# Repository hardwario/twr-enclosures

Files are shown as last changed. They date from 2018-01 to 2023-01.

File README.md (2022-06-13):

<a href="https://www.hardwario.com/">HARDWARIO Logo</a>

# HARDWARIO Enclosures

This repository contains Openscad and STL models of HARDWARIO IoT Kit enclosures. These model have been optimized for 3D printing.

# Overview

The following table lists the available models:

| _____Model/Preview | STL Model | _____Module/setup | #Layers | #Mini | #Standard | #Tag | I/O Terminal | Antenne | USB | Compatibility |
| --- | --- | --- | --- | ----- | --- | ---- | --- | --- | --- | --- |
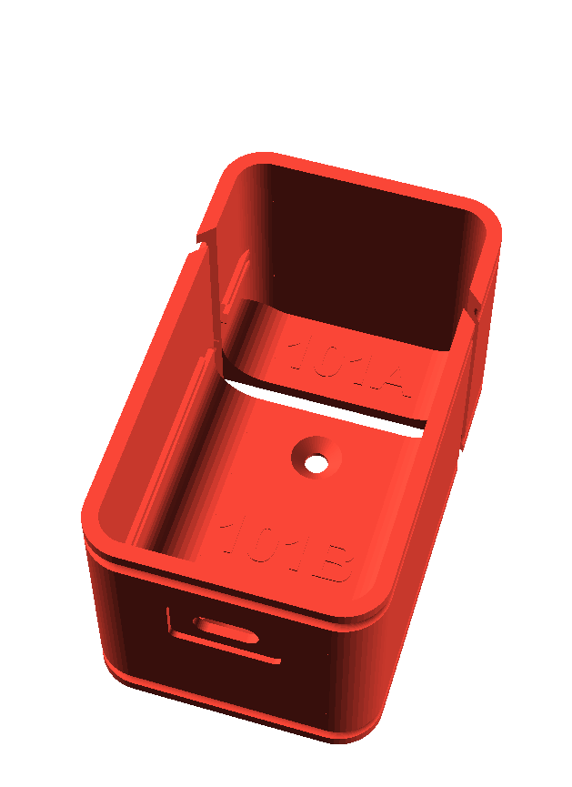
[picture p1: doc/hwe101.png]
|  | HWE101A<br>HWE101B | Mini Battery<br>Core<br>Mini Cover\* | 3 | 3 | \- | \- | \- | \- | Yes | |
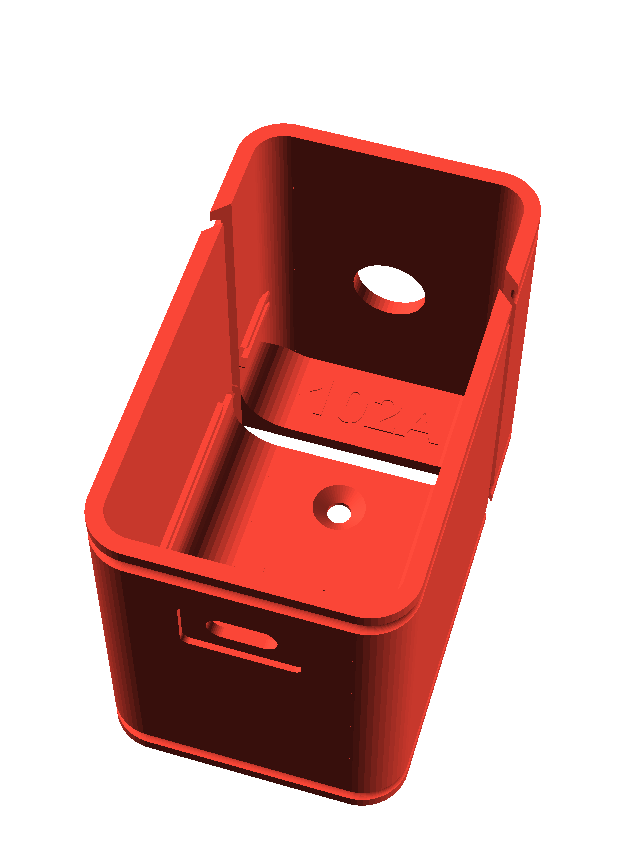
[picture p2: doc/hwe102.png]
|  | HWE102A<br>HWE102B | Mini Battery<br>LoRa / Sigfox<br>Core<br>Mini Cover\* | 4 | 4 | \- | \- | \- | Yes | Yes | |
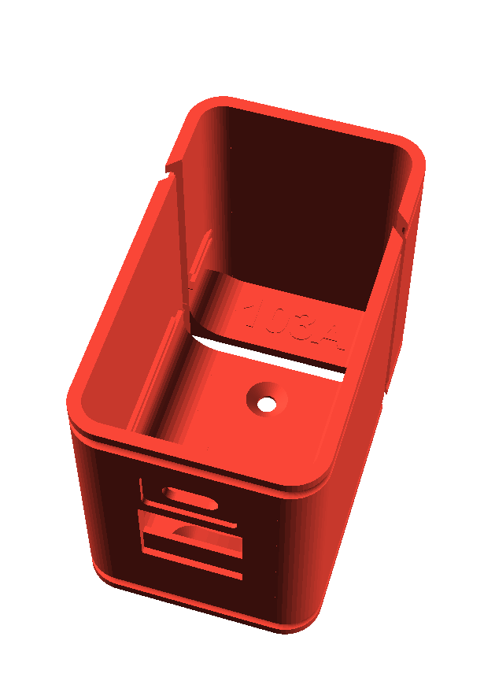
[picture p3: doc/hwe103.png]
|  | HWE103A<br>HWE103B | Mini Battery<br>RS-485<br>Core<br>Mini Cover\* | 4 | 4 | \- | \- | 4P/3.5 mm | \- | Yes | 1-Wire R1.1<br>Sensor R1.0 |
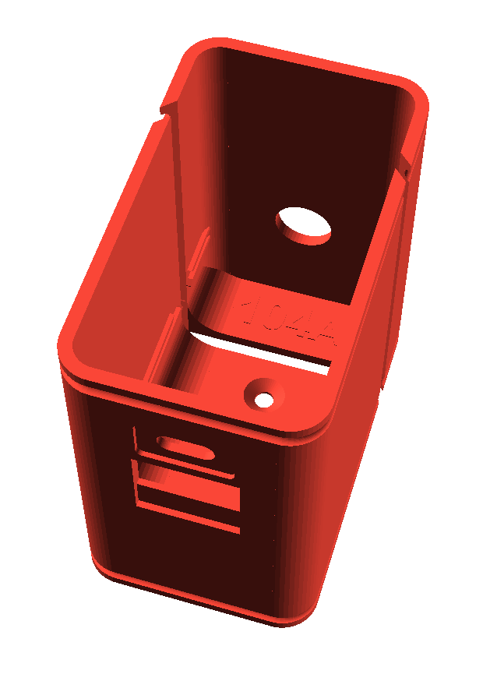
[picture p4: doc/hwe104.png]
|  | HWE104A<br>HWE104B | Mini Battery<br>LoRa / Sigfox<br>RS-485<br>Core<br>Mini Cover\* | 5 | 5 | \- | \- | 4P/3.5 mm | Yes | Yes | 1-Wire R1.1<br>Sensor R1.0 |
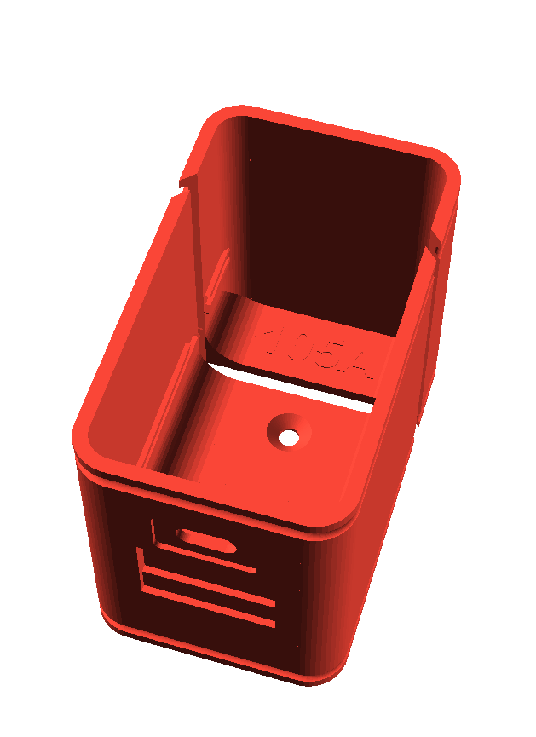
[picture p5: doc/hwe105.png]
|  | HWE105A<br>HWE105B | Mini Battery<br>Sensor R1.1<br>Core<br>Mini Cover\* | 4 | 4 | \- | \- | 5P/3.5 mm | \- | Yes | |
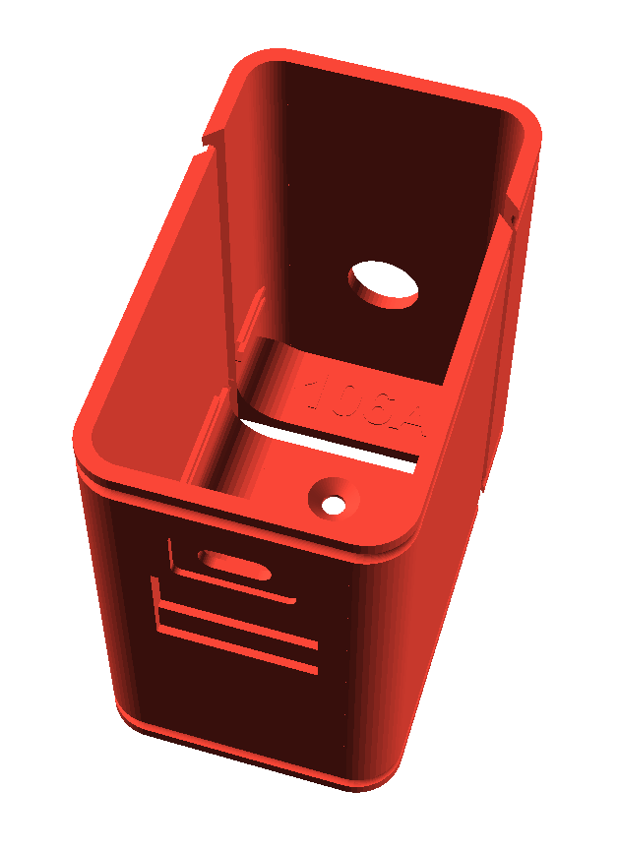
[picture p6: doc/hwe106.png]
|  | HWE106A<br>HWE106B | Mini Battery<br>LoRa / Sigfox<br>Sensor R1.1<br>Core<br>Mini Cover\* | 5 | 5 | \- | \- | 5P/3.5 mm | Yes | Yes | |
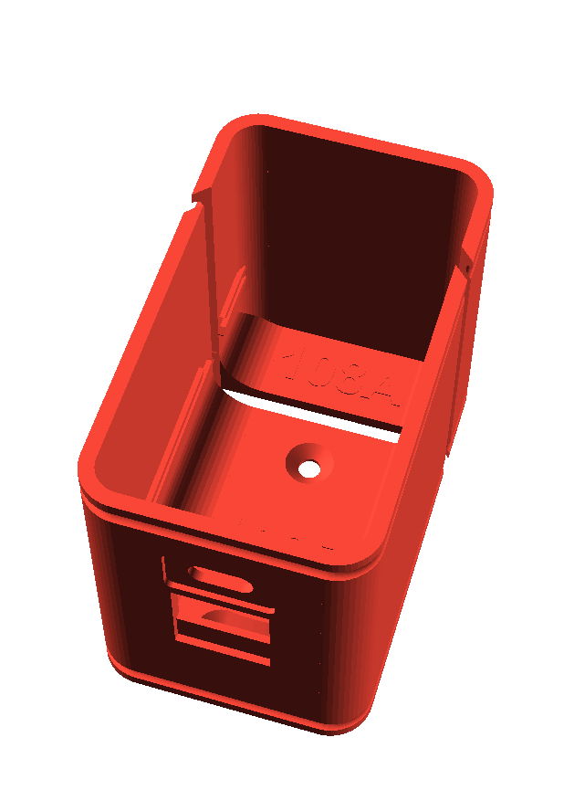
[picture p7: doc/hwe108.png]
|  | HWE108A<br>HWE108B | Mini Battery<br>Relay<br>Core<br>Mini Cover\* | 4 | 4 | \- | \- | 3P/3.81 mm | \- | Yes | |
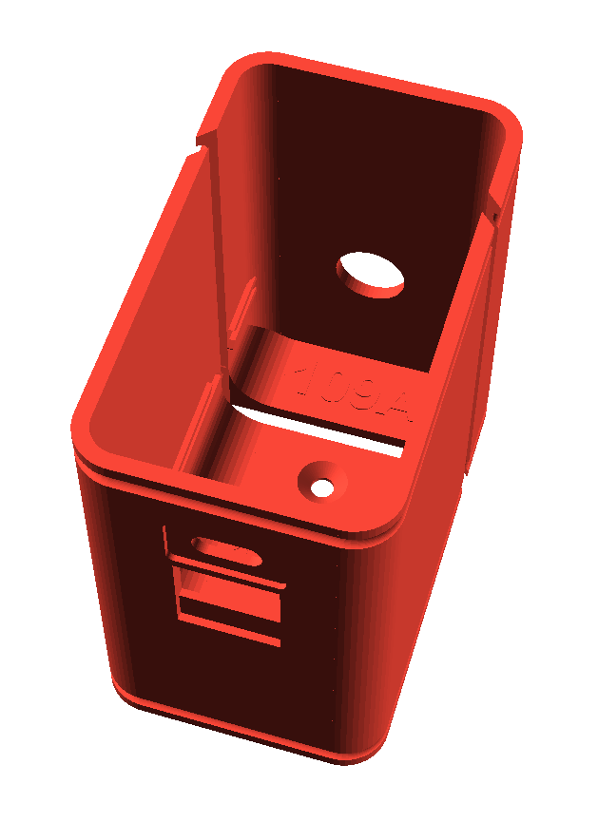
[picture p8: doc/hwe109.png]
|  | HWE109A<br>HWE109B | Mini Battery<br>LoRa / Sigfox<br>Relay<br>Core<br>Mini Cover\* | 5 | 5 | \- | \- | 3P/3.81 mm | \- | Yes | |
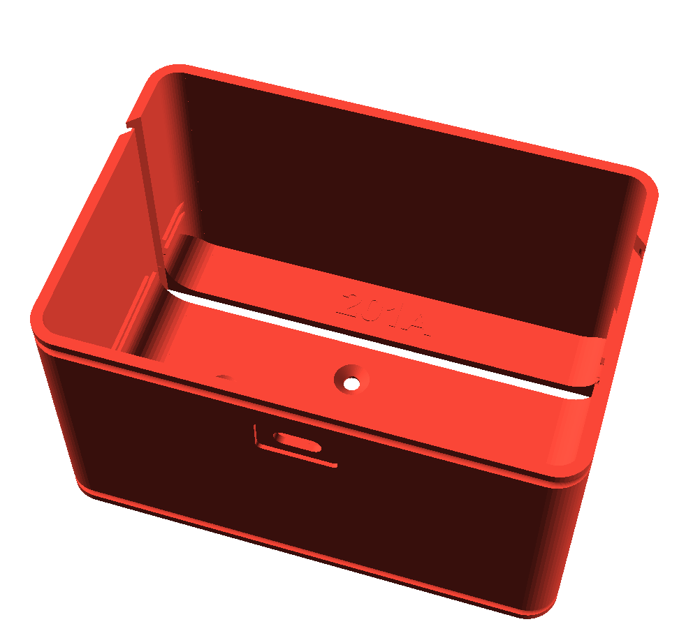
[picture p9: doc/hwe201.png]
|  | HWE201A<br>HWE201B | Battery<br>CO2 (+ 3xTag)<br>Core<br>Cover | 4 | 4 | 1 | 3 | \- | \- | Yes | |
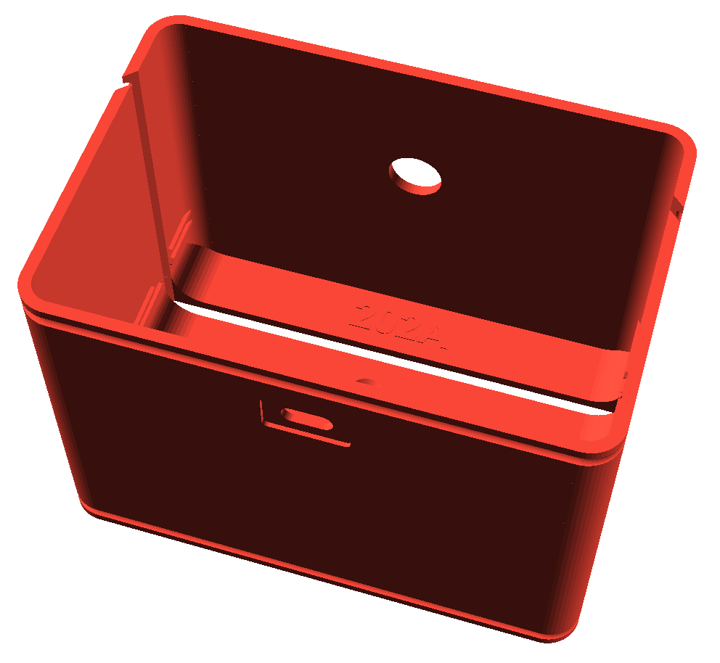
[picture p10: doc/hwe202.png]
|  | HWE202A<br>HWE202B | Battery<br>CO2 (+ 3xTag)<br>LoRa / Sigfox<br>Core<br>Cover | 5 | 5 | 2 | 3 | \- | Yes | Yes | |
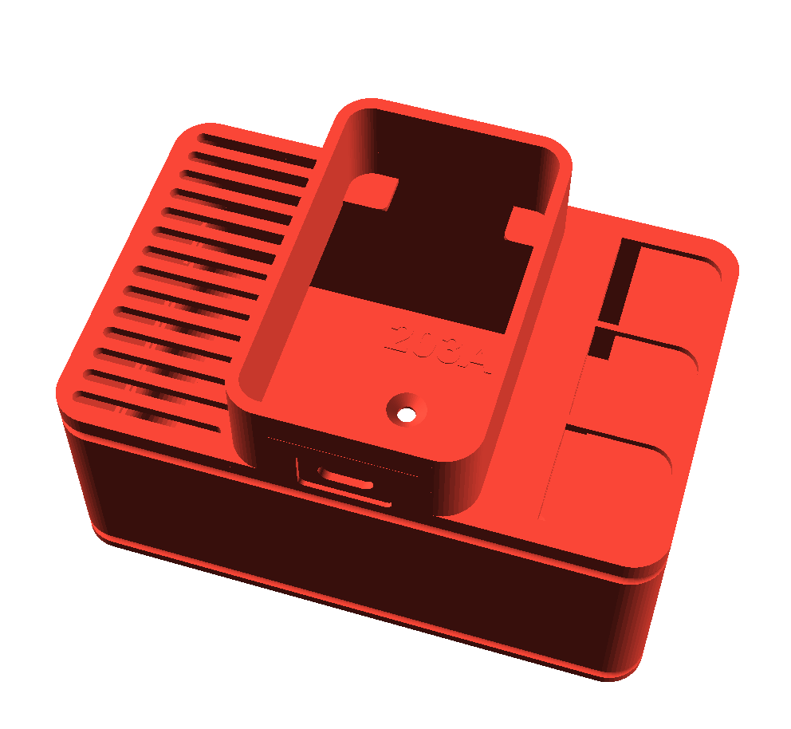
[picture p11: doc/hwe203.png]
|  | HWE203A<br>HWE203B | Battery<br>CO2 (+3xTag inner)<br>Core<br>LCD\* | 4 | 4 | 2 | 3 | \- | \- | Yes | |
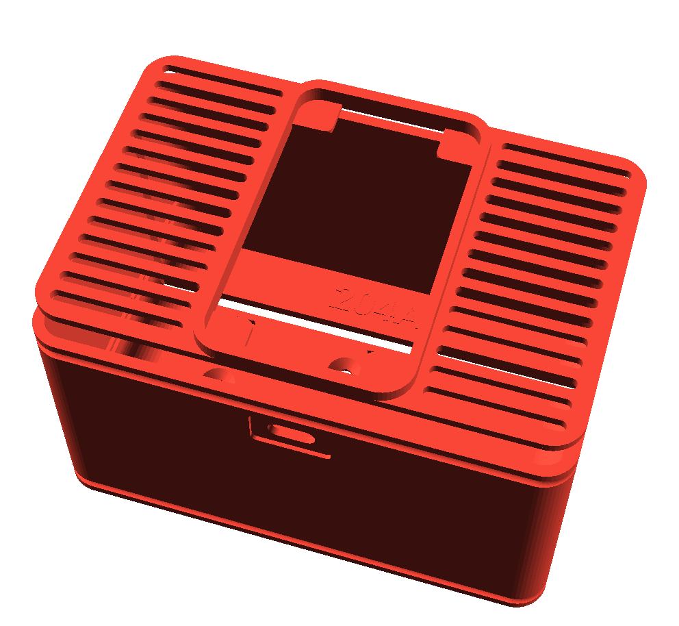
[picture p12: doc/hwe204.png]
|  | HWE204A<br>HWE204B<br>HWE204C | Battery<br>CO2 (+ 3xTag)<br>Core<br>LCD\* | 4 | 4 | 2 | 3 | \- | \- | Yes | |
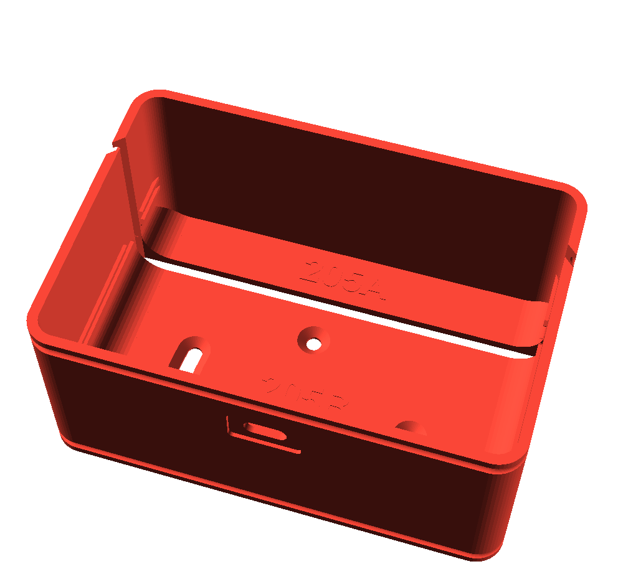
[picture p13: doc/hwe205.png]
|  | HWE205A<br>HWE205B | Battery (+ 1xTag)<br>Core<br>Cover | 3 | 3 | 1 | 1 | \- | \- | Yes | |
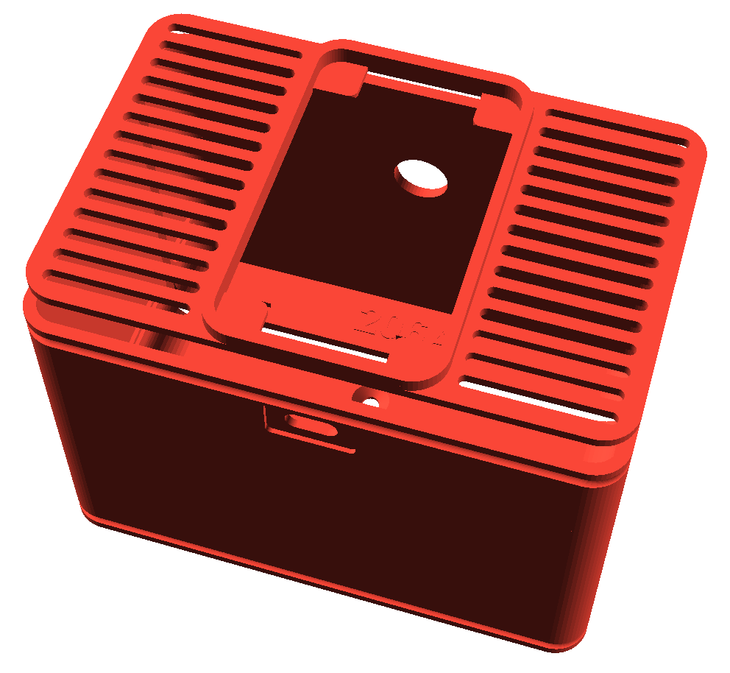
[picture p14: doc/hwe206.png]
|  | HWE206A<br>HWE206B<br>HWE206C | Battery<br>CO2 (+ 3xTag)<br>LoRa / Sigfox<br>Core<br>LCD\* | 5 | 5 | 3 | 3 | \- | Yes | Yes | |
|  | HWE207A<br>HWE207B | Battery<br>LoRa / Sigfox<br>Core<br>Cover\* | 4 | 2 | 2 | 1 | \- | Yes | Yes | |
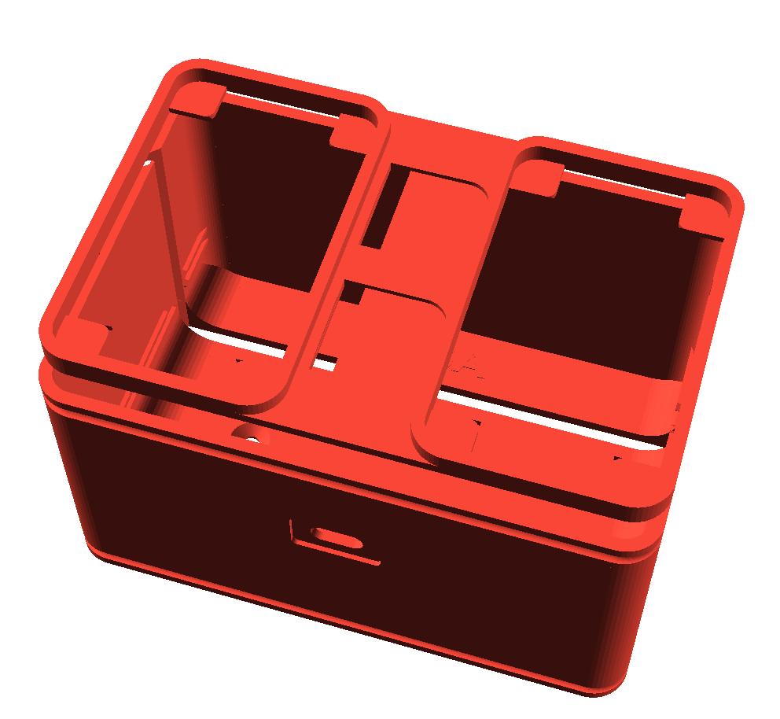
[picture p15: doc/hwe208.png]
|  | HWE208A<br>HWE208B<br>HWE208C | Battery (+ 1xTag)<br>Core<br>Split<br>LCD\* & Climate\* (+ 2xTag) | 4 | 4 | 3 | 3 | \- | No | Yes | |
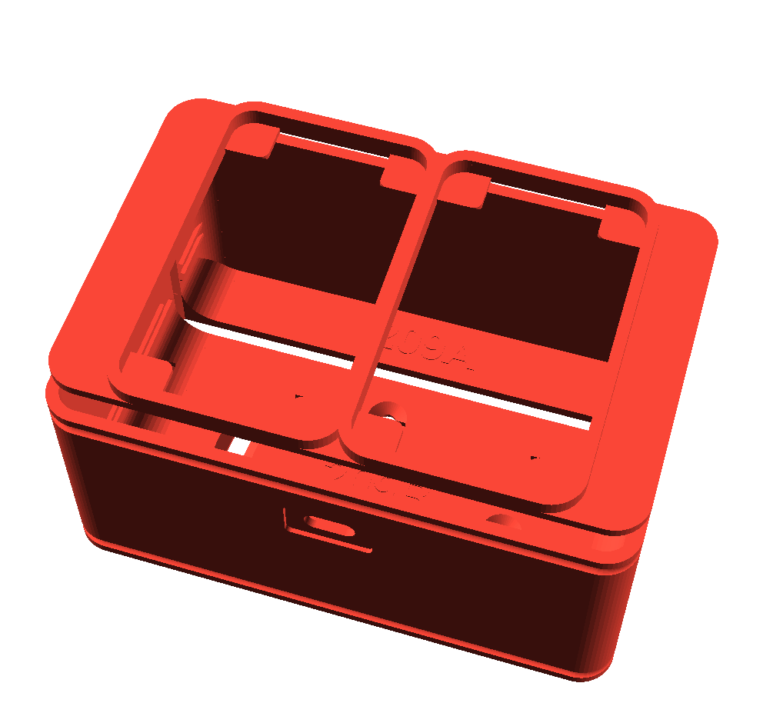
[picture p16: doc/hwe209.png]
|  | HWE209A<br>HWE209B<br>HWE209C | Battery (+ 1xTag)<br>Core<br>Compact Split<br>LCD\* & Climate\* | 4 | 4 | 3 | 1 | \- | No | Yes | |
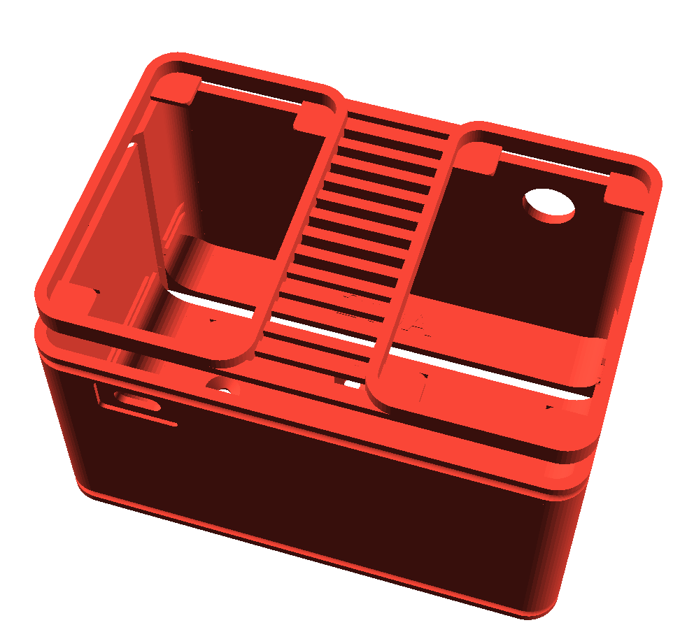
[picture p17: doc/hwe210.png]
|  | HWE210A<br>HWE210B<br>HWE210C | Battery (+ 1xTag)<br>Split<br>Core & LoRa / SF<br>LCD\* & Climate\*  | 4 | 4 | 3 | 1 | \- | Yes | Yes | |
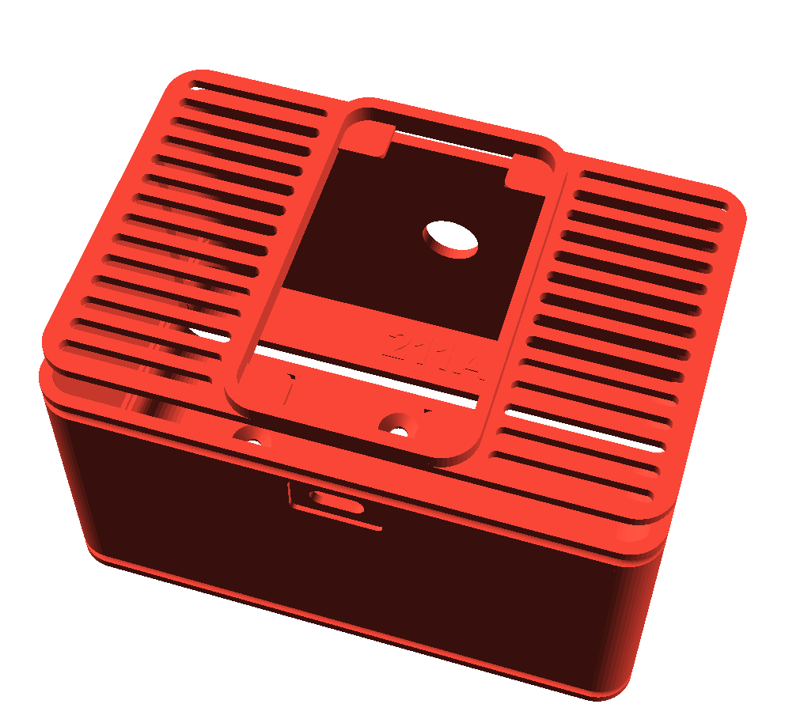
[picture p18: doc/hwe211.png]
|  | HWE211A<br>HWE211B<br>HWE211C | Battery (+ 1xTag)<br>LoRa / Sigfox<br>Core<br>LCD\* | 4 | 4 | 3 | 1 | \- | \- | Yes | |
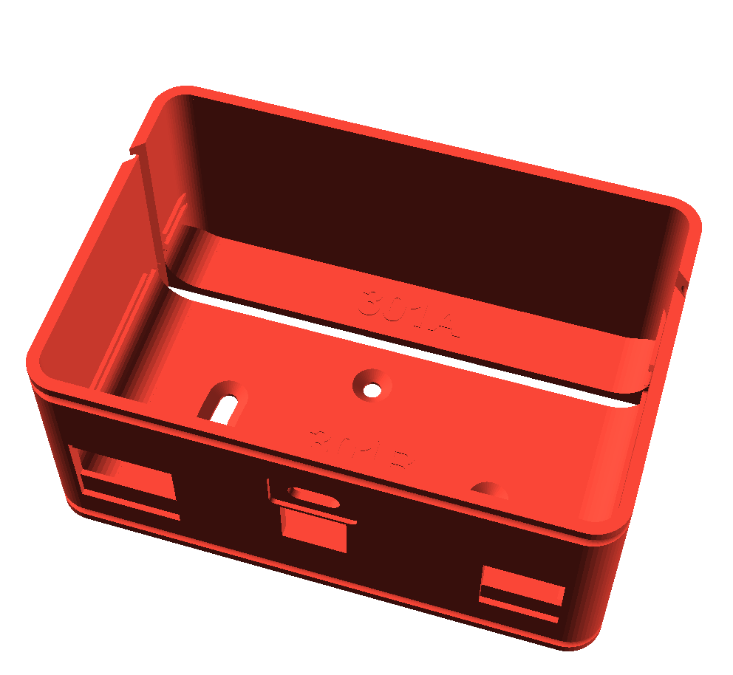
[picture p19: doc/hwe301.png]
|  | HWE301A<br>HWE301B | Power (+ 2xTag)<br>Core<br>Cover | 3 | 3 | 1 | 2 | 3P/3.81 mm 3P/5.0 mm | \- | Yes | |
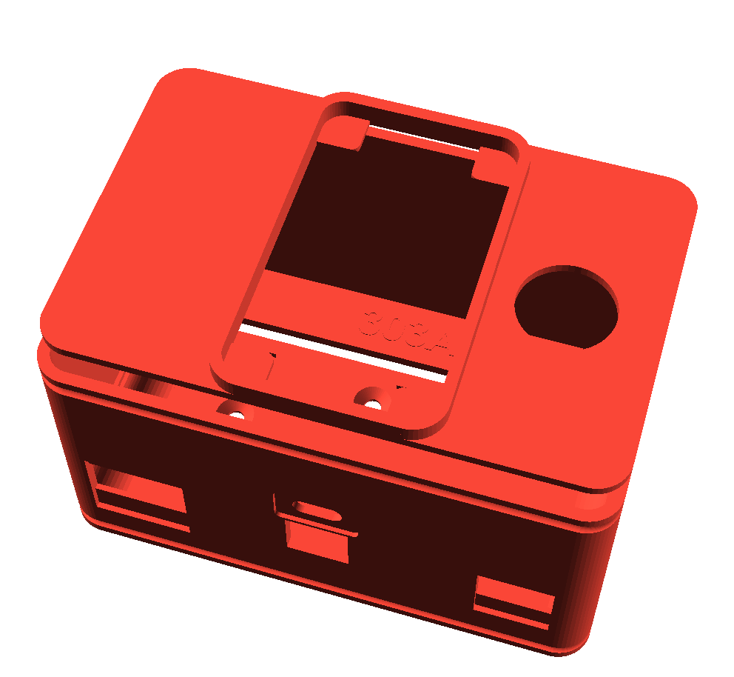
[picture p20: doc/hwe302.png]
|  | HWE302A<br>HWE302B<br>HWE302C | Power (+ 2xTag)<br>Core<br>Encoder | 3 | 3 | 1 | 2 | 3P/3.81 mm 3P/5.0 mm | \- | Yes | |
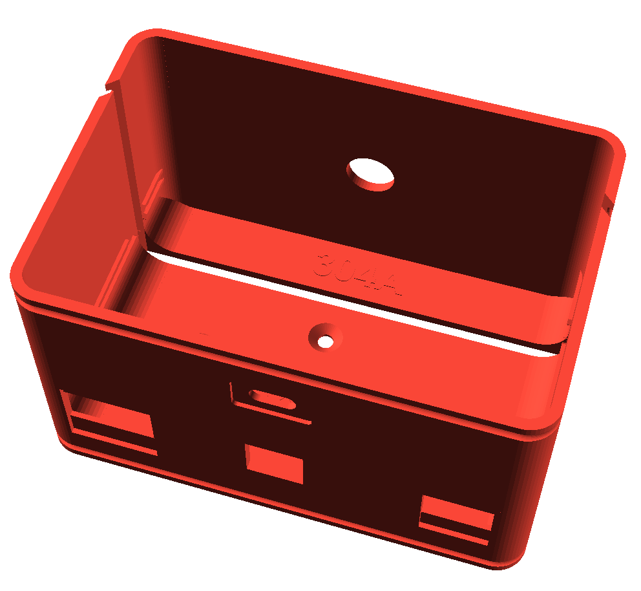
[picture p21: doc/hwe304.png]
|  | HWE304A<br>HWE304B | Power (+ 2xTag)<br>LoRa / Sigfox<br>Core<br>Cover | 4 | 4 | 2 | 2 | 3P/3.81 mm 3P/5.0 mm | Yes | Yes | |
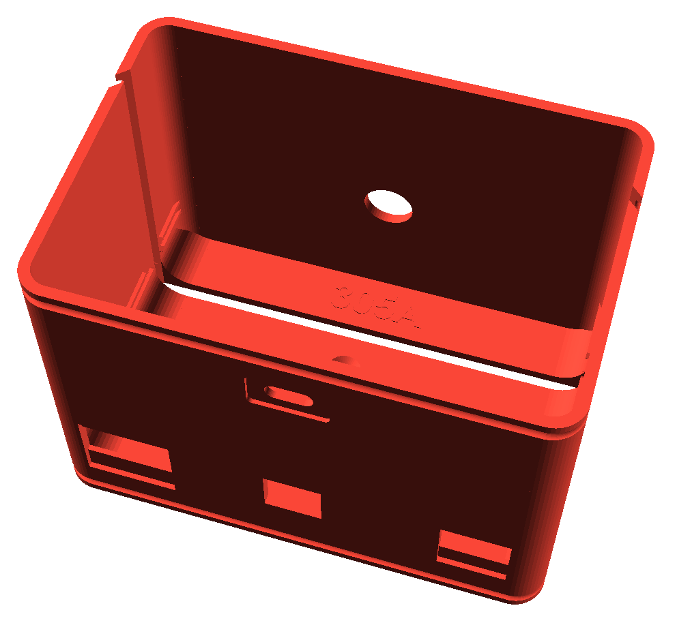
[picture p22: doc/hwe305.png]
|  | HWE305A<br>HWE305B | Power (+ 2xTag)<br>LoRa / Sigfox<br>CO2 (+ 3xTag)<br>Core<br>Cover | 5 | 3 | 2 | 5 | 3P/3.81 mm 3P/5.0 mm | Yes | Yes | |
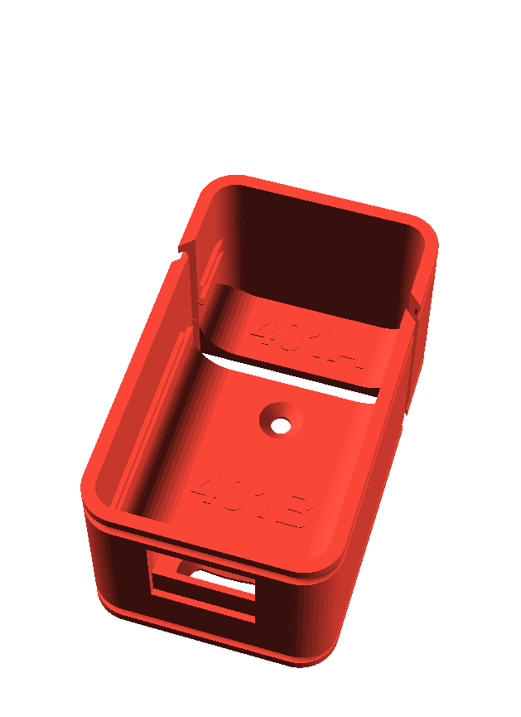
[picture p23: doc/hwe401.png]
|  | HWE401A<br>HWE401B | 1-Wire<br>Climate | 2 | 2 | 2 | \- | 4P/3.5 mm | \- | \-  | |
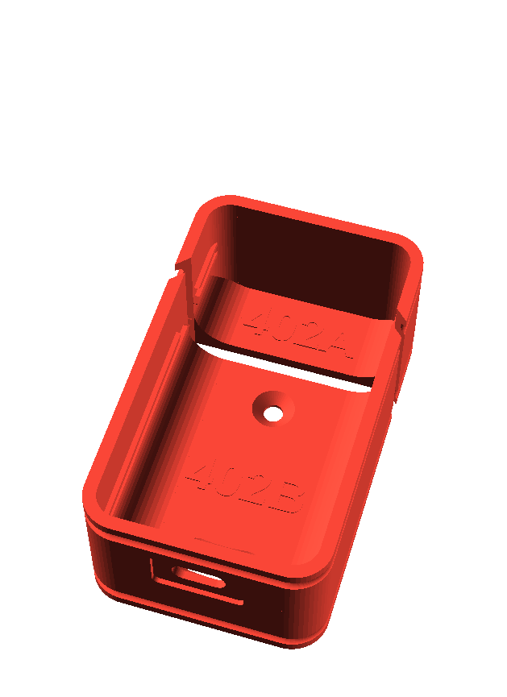
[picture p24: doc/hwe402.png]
|  | HWE402A<br>HWE402B | Bridge<br>Climate / Humidity Tag | 1 | 1 | 1 | 1 | \- | \- | Yes | |
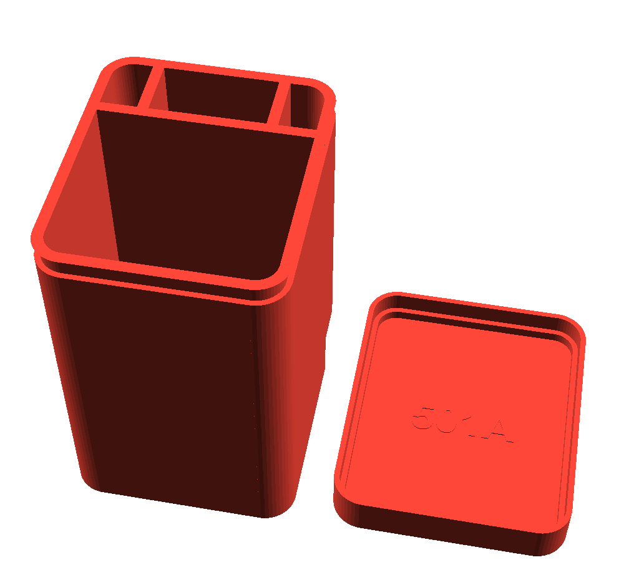
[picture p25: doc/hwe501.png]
|  | HWE501A<br>HWE501B | Mini Battery<br>Sensor + Flood Detector<br>Core | 3 | 3 | \- | \- | \- | \- | \-  | |
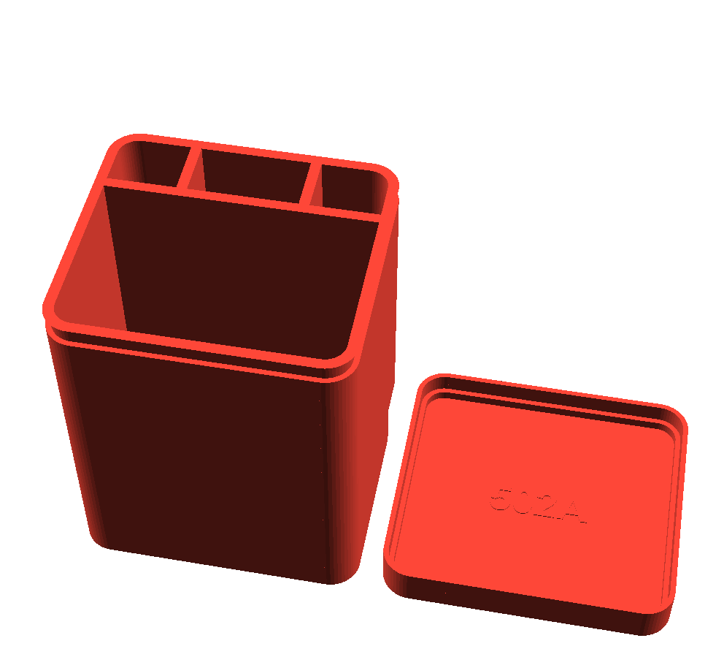
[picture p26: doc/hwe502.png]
|  | HWE502A<br>HWE502B | Mini Battery<br>Sensor + Flood detector<br>Core<br>LoRa / Sigfox | 4 | 4 | \- | \- | \- | Yes | \-  |

> *Note: As top floor these Modules are available: Mini Cover, LED, PIR, CLIMATE, GPS or Infra Grid Module

>All STL models are tested and optimized for 3D printer Prusa I3 MK2, print resolution 0.2 mm or better.

List of available accessories:

| Model  | Description | Picture |
|---|---|---|
| PIR-CV-R1 | Flat Cover for PIR Module<br> | |
| PIR-SC-R1 | PIR Cover Hat<br> | |
| LED-HD-R1 | Holder for 3mm LED or phototransistor SFH 3310 | |
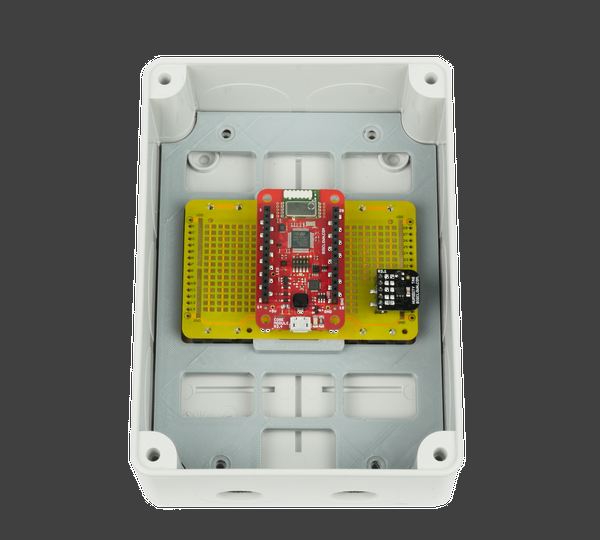
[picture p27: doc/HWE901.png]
| HWE901 | Platform for  ABB 00852 enclosure for installing Battery Module or Power Module and up to 3 other modules| |

> Models are tested and optimized for 3D printer Prusa I3 MK2, print resolution 0.15 mm.

# License

This project is licensed under the [Attribution-ShareAlike 4.0 International](https://creativecommons.org/licenses/by-sa/4.0/) - see the [LICENSE](LICENSE) file for details.

---

Made with &#x2764;&nbsp; by [HARDWARIO a.s.](https://www.hardwario.com) in Czech Republic.

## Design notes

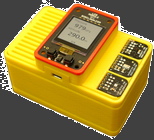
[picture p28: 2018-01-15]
doc/bce203-1.png

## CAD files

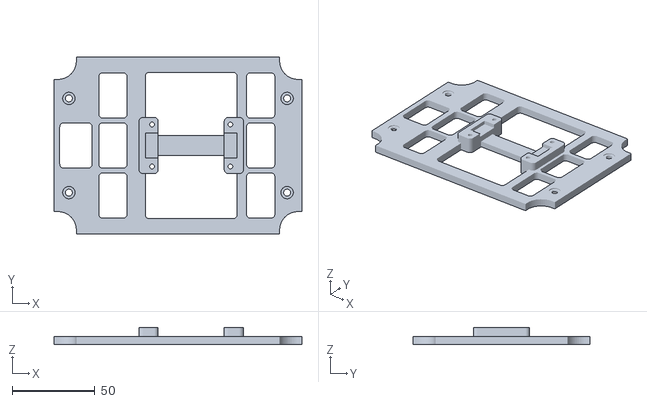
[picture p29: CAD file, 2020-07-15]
stl-models/HWE901.stl
150.0 x 107.0 x 10.5

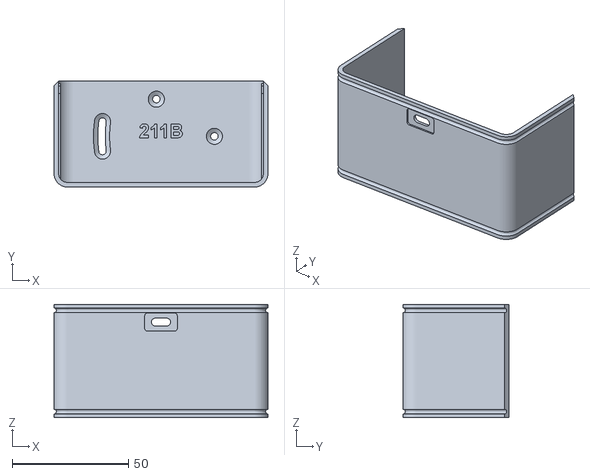
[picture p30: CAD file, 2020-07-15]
stl-models/HWE211B.stl
92.2 x 45.7 x 48.8

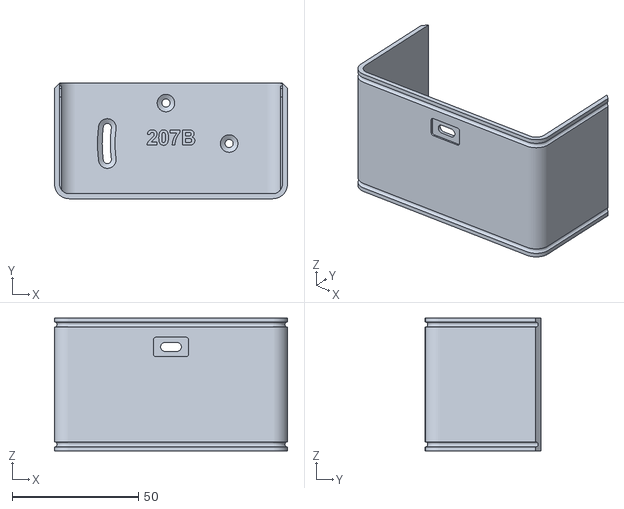
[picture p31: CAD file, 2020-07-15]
stl-models/HWE207B.stl
92.2 x 45.7 x 52.6

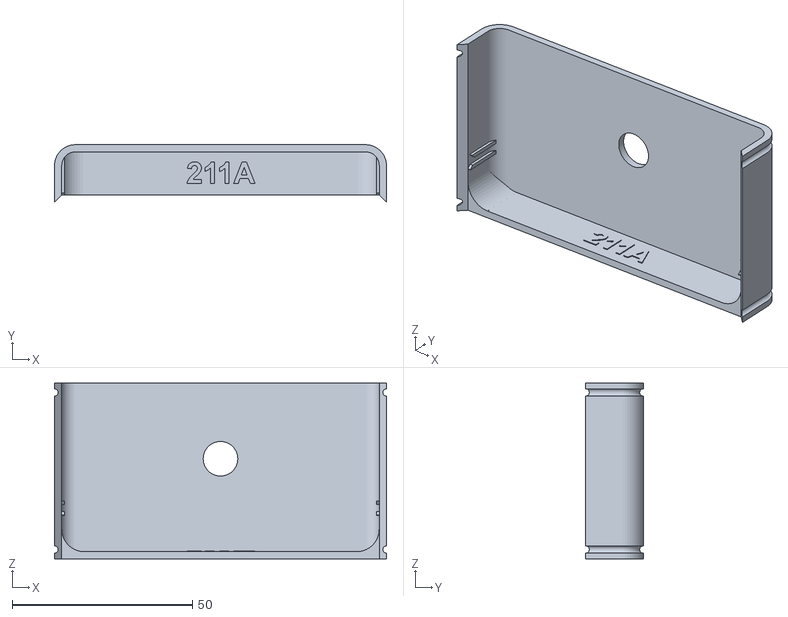
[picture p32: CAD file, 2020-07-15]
stl-models/HWE211A.stl
92.2 x 16.0 x 48.8

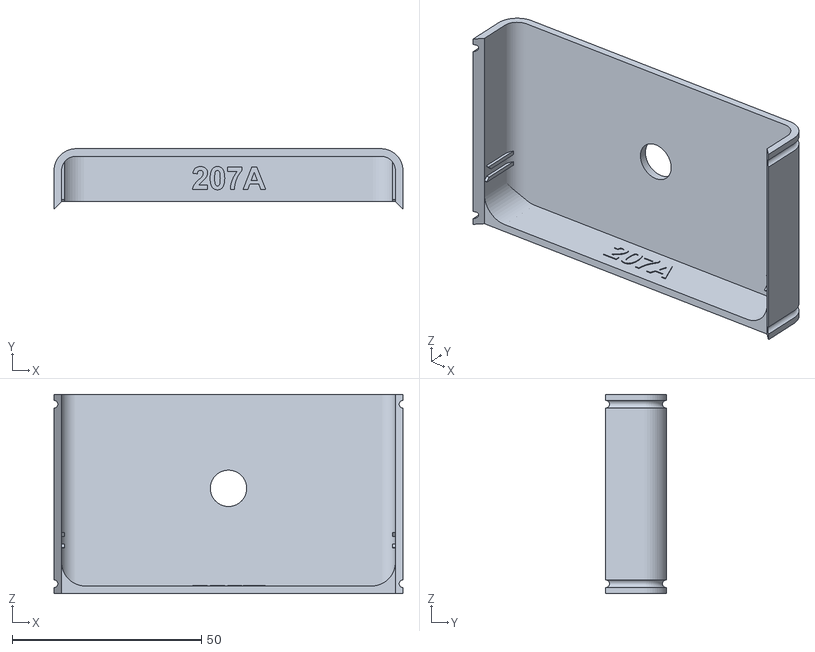
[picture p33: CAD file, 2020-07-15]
stl-models/HWE207A.stl
92.2 x 16.0 x 52.6

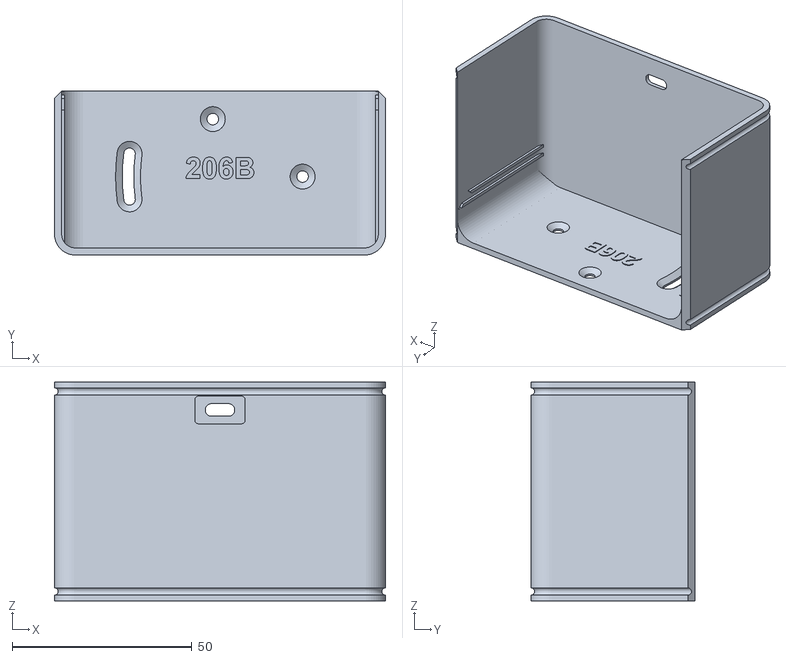
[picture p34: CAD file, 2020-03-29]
stl-models/HWE206B.stl
92.2 x 45.7 x 60.9

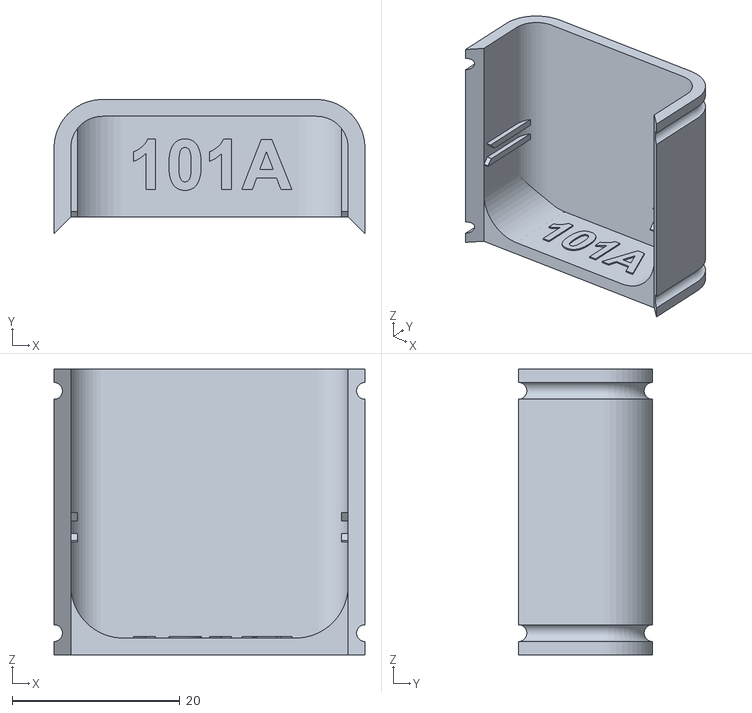
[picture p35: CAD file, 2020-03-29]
stl-models/HWE101A.stl
37.1 x 16.0 x 34.1

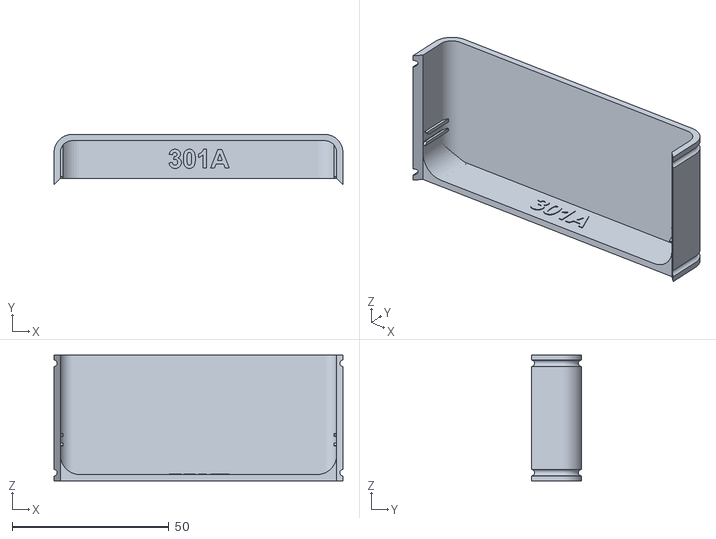
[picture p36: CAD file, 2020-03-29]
stl-models/HWE301A.stl
92.2 x 16.0 x 40.1

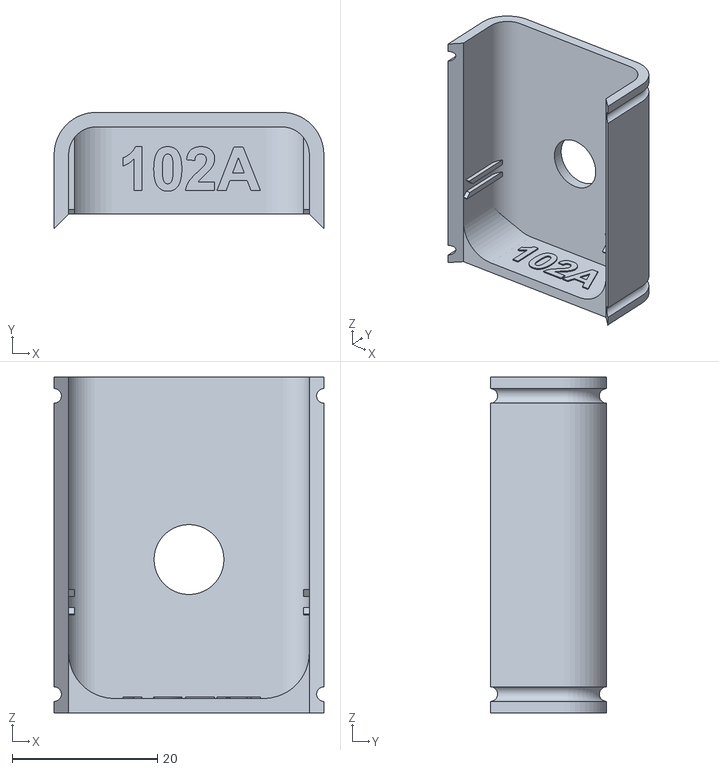
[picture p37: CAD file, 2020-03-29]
stl-models/HWE102A.stl
37.1 x 16.0 x 46.2

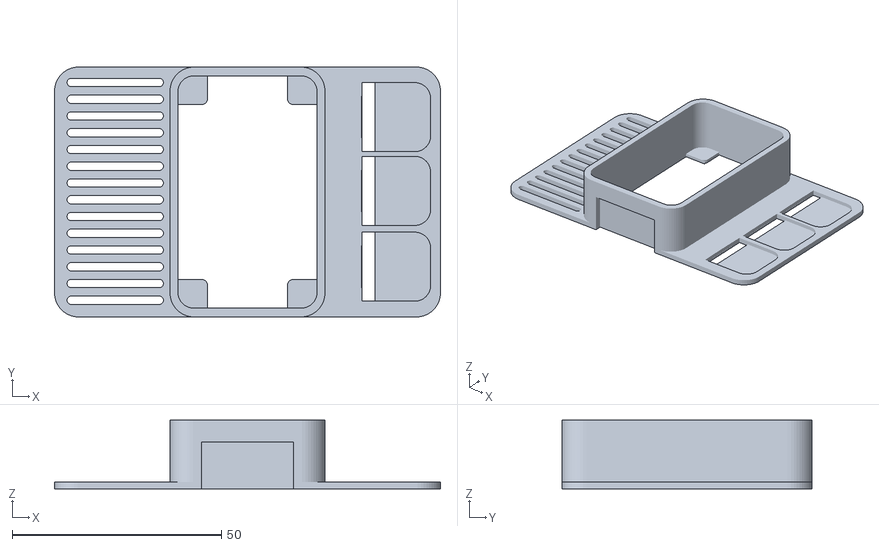
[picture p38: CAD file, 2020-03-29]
stl-models/HWE203C.stl
92.2 x 59.7 x 16.4

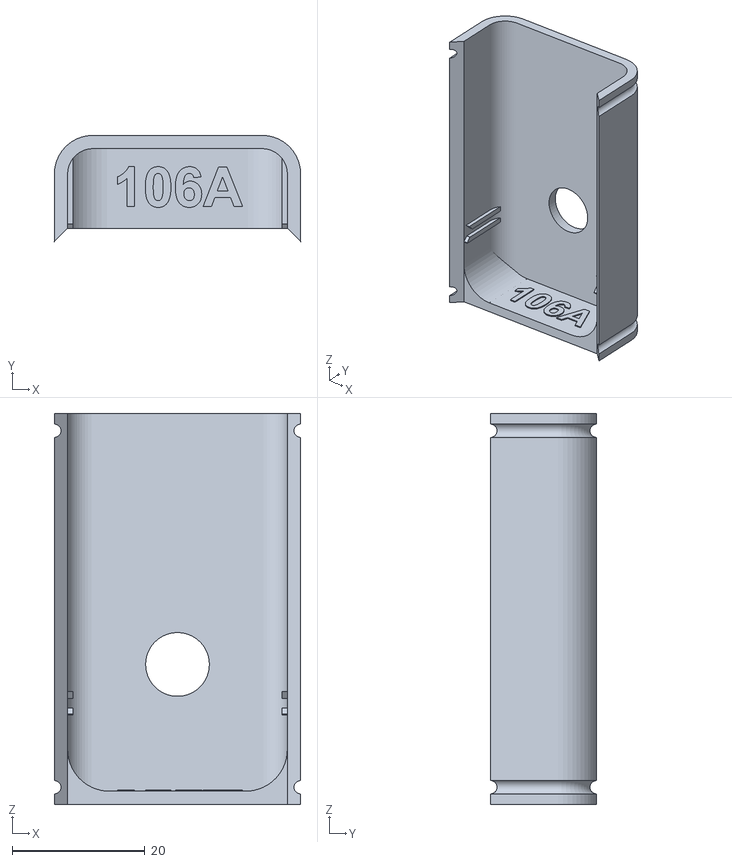
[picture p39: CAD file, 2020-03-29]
stl-models/HWE106A.stl
37.1 x 16.0 x 58.9

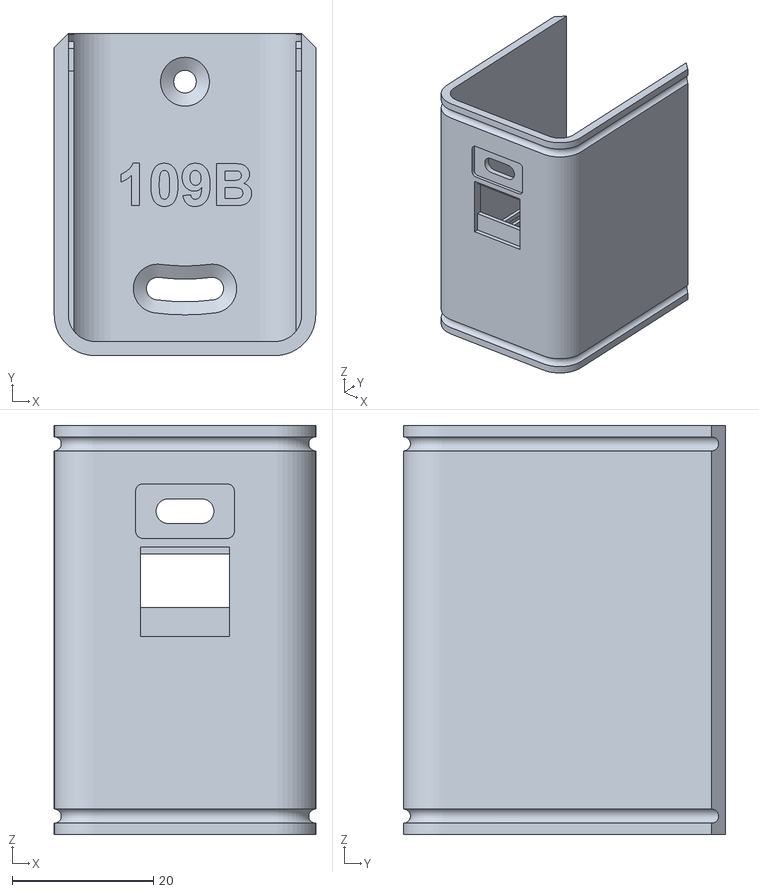
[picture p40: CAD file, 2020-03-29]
stl-models/HWE109B.stl
37.1 x 45.7 x 58.0

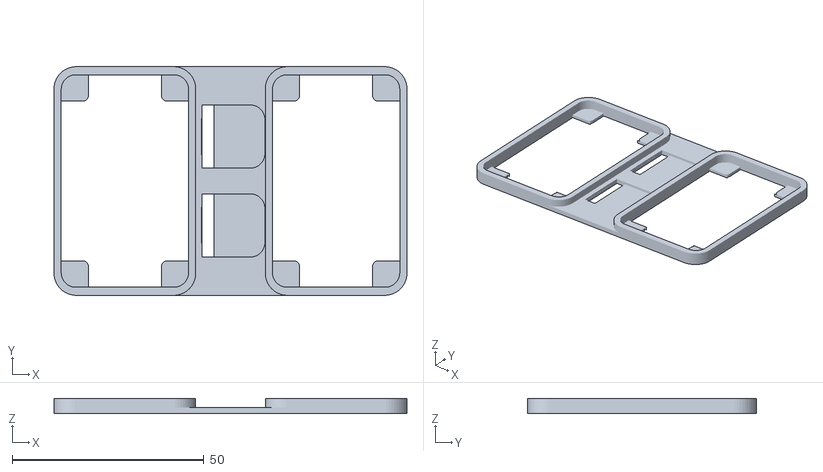
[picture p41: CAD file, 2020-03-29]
stl-models/HWE208C.stl
92.2 x 59.7 x 4.00

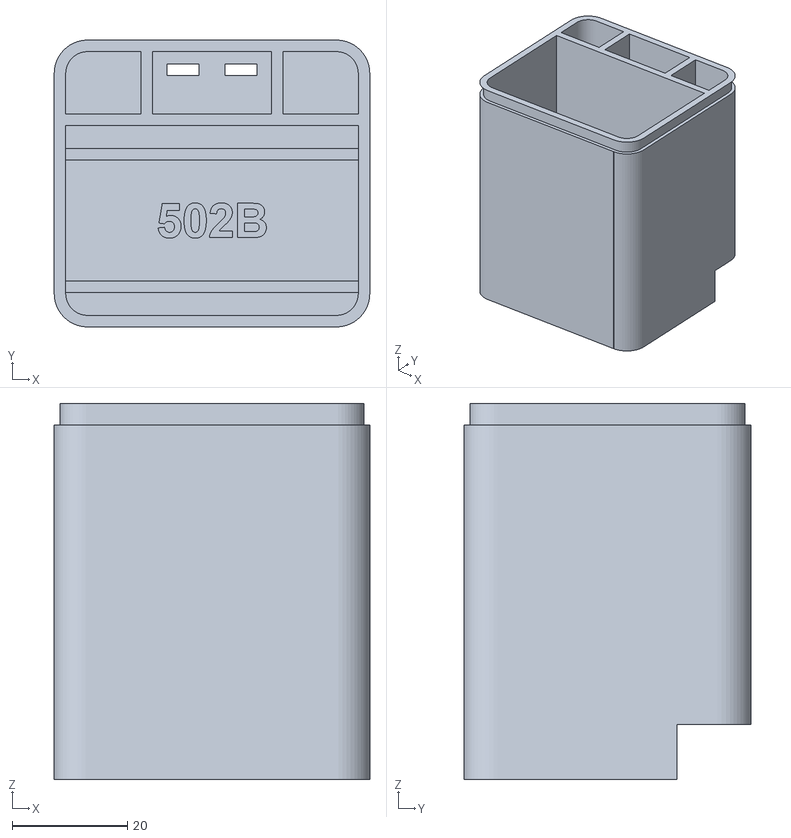
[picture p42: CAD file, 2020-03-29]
stl-models/HWE502B.stl
54.8 x 49.8 x 65.3

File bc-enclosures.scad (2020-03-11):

use <MCAD/boxes.scad>;
use <MCAD/triangles.scad>;
 
 
//parameter: "A" = part A; "B" = part B; "C" = cover; "ALL" all box 

//BCE101r2("B"); //Mini Battery + Core R2 + Mini Cover
//BCE102r2("A"); //Mini Battery + Sigfox + Core R2 + Mini Cover
//BCE103r2("B"); //Mini Battery + 1-Wire + Core R2 + Mini Cover
//BCE104r2("B"); //Mini Battery + Sigfox + 1-Wire + Core R2 + Mini Cover
//BCE105r2("B"); //Mini Battery + Sensor R1.1 + Core R2 + Cover
//BCE106r2("B"); //Mini Battery + Sigfox + Sensor R1.1 + Core R2+ Cover
//BCE108r2("B"); //Mini Battery + Relay + Core R2 + Mini Cover
//BCE109r2("B"); //Mini Battery + Sigfox + Relay + Core R2 + Mini Cover
//BCE121r2 ("ALL"); //1-Wire + Cover
//BCE122 ("A"); //Bridge + Tag
//BCE201r2("B"); //Battery + CO2 + Core R2+ Cover
//BCE202r2("A"); //Battery R1.3 + CO2 + Sigfox + Core R2 + Cover
BCE202r14("B"); //Battery R1.4 + CO2 + Sigfox + Core R2 + Cover
//BCE203r2("B"); //Battery + CO2 + Core R2+ LCD (Tags ouside)
//BCE204r2("C"); //Battery + CO2 + Core R2+ LCD (Tags inside)
//BCE205r2("B"); //Battery + Core R2 + Cover
//BCE206r2("B"); //Battery + CO2 + Sigfox + Core R2 + LCD (Tags inside)
//BCE208r2 ("A"); //Battery + Core R2 + Split + LCD & PIR (or LCD & Climate) & 2x Tag (intside)
//BCE209r2 ("A"); //Battery + Core R2 + Compact Split + LCD & Climate
//BCE210r2("C"); //Battery + Split Core R2 & Split + LCD & GPS (or PIR & Climate) & No Tag
//BCE211r2("C"); //Battery + Sigfox + Core R2+ LCD (Tags inside)
//BCE301r2("B"); //Power + Core R2 + Cover
//BCE302r2 ("ALL"); //Power + Core R2 + Encoder
//BCE303r2 ("ALL"); //Power + Core R2 + Encoder + LCD
//BCE302r2 ("ALL"); //Power + Core R2 + Encoder
//BCE304r2("B"); //Power + Sigfox + Core R2 + Cover
//BCE305r2("B"); //Power + Sigfox + CO2 + Core R2 + Cover
//BCE501 ("A"); //Mini Battery + Sensor + Core + Flood Detector
//BCE502 ("A"); //Mini Battery + Sensor + Core + Sigfox + Flood Detector
 
 
wall=2.0;   // Wall Thickness
length= 55.7; 
cut_length = 16; //Part A / B cut

// Mounting holes params
screw_hole_height = 2.1;
screw_size = 3.2;
screw_hole_angle = 15;
screw_hole_top_size = screw_size+4;
 
//Holder for PCB
holder_w = 0.8;
holder_h = 1;
holder_short = 7; // multiplier of top holder shortcut (=1 the same as bottom holder)
   
// Corner Radius
radius=3.8; // radius
radius_bot=3.8+2.5; //inner radius of bottom
 
//Rubber ring
ring_r = 1;
ring_top_pos = 2.6;
ring_bottom_pos = 2.6;
 
cut_type = 0; // [1: old, 0: new]
 
// Get outside mesurments

/* [Advanced] */
sidesonly=1; // [0:No, 1:Yes] round the sides of the box?
previw_mode = 0; //[0:No, 1:Yes] 1 for faster rendering
step = 8; // resolution of ring corner - STEP in degrees
$fn = 50; // RESOLUTION
r_MiniUSB=1;
r_wifi_antenna = 4.8;
 
PCB_height=1.1;
fatPCB_height=1.6;
MiniPCB_width=33; 
PCB_width=88;
PCB_radius=3.8; 
 
USBmicro_height=5.7;  
USBmicro_width=12;
USBmicro_length=wall/2;
USBmicro_hole=3.5;
USBmicro_hole_span=8.2;

flood_detector_width=10.8;
flood_detector_length=20.7;
flood_detector_contact_width=2;
flood_detector_contact_length=5.5;
  
terminal185mm_height=7.6;
terminal185mm_width=19;
terminal185mm_length=wall;
terminal185mm_upper_recess=1;
terminal185mm_bottom_recess=4;

terminal17mm_height=8.5;
terminal17mm_width=17;
terminal17mm_length=wall;
terminal17mm_upper_recess=2.5;
terminal17mm_bottom_recess=4.8;

terminal15mm_height=7.7;
terminal15mm_width=15.5;
terminal15mm_length=wall;
terminal15mm_upper_recess=1;
terminal15mm_bottom_recess=4.8;

terminal12_3mm_height=7.6;
terminal12_3mm_width=12.6;
terminal12_3mm_length=wall;
terminal12_3mm_upper_recess=1;
terminal12_3mm_bottom_recess=4.1;
 
key_width_wall=0.2;
key_length_wall=wall;
key_height_wall=1.6;
key_x_roof=8.2;
key_y_roof=wall;
key_height_roof=0.35;


module BCE101r2 (value) { //Mini Battery + Core R2 + Mini Cover
    width= 33.1; 
    height= 32.1;
    holder_diff = 1.25;
    holder_pos = 13;   

        difference() {
            translate([0,0,height/2+wall/2]) {
                hollowbox(width, height, holder_diff, value); 
                holder(width, height, holder_diff, holder_pos, value);
                }
            translate([0,0, 19])
                MiniCore2R21();
            translate([0, 9, 0])
                mountingHoles1xx();            
        }
}
module BCE102r2 (value) { //Mini Battery + Sigfox + Core R2 + Mini Cover
    width= 33.1; 
    height= 44.2;
    holder_diff = 1.25;
    holder_pos = 13;   

        difference() {
            translate([0,0,height/2+wall/2]) {
                hollowbox(width, height, holder_diff, value); 
                holder(width, height, holder_diff, holder_pos, value);
                }
            translate([0,0, 31.6])
                MiniCore2R21();
            translate([0,0, 19])
                MiniSigfoxR21();
            translate([0, 9, 0])
                mountingHoles1xx();            
        }
}
module BCE103r2 (value) { //Mini Battery + 1-Wire + Core R2 + Mini Cove
    width= 33.1; 
    height= 44.4;
    holder_diff = 1.25;
    holder_pos = 13;   

        difference() {
            translate([0,0,height/2+wall/2]) {
                hollowbox(width, height, holder_diff, value); 
                holder(width, height, holder_diff, holder_pos, value);
                }
            translate([0,0, 31.6])
                MiniCore2R21();
            translate([0,0, 19])
                MiniSensorModuleR10();
            translate([0, 9, 0])
                mountingHoles1xx();            
        }
}
module BCE104r2 (value) { //Mini Battery + Sigfox + 1-Wire + Core R2 + Mini Cover
    width= 33.1; 
    height= 57.1;
    holder_diff = 1.25;
    holder_pos = 13;   

        difference() {
            translate([0,0,height/2+wall/2]) {
                hollowbox(width, height, holder_diff, value); 
                holder(width, height, holder_diff, holder_pos, value);
                }
                            
            translate([0,0, 44.1])
                MiniCore2R21();        
            translate([0,0, 31.8])
                MiniSensorModuleR10();
            translate([0,0, 18.9])
                MiniSigfoxR21();
            translate([0, 9, 0])
                mountingHoles1xx();            
        }
}
module BCE105r2 (value) { //Mini Battery + Sensor R1.1 + Core R2 + Cover
    width= 33.1; 
    height= 44.2;
    holder_diff = 1.25;
    holder_pos = 13;   

        difference() {
            translate([0,0,height/2+wall/2]) {
                hollowbox(width, height, holder_diff, value); 
                holder(width, height, holder_diff, holder_pos, value);
                }
       
            translate([0,0, 31.2])
                MiniCore2R21();
            translate([0,0, 18.4])
                MiniSensorModuleR11();
            translate([0, 9, 0])
                mountingHoles1xx();            
        }
}
module BCE106r2 (value) { //Mini Battery + Sigfox + Sensor R1.1 + Core R2+ Cover
    width= 33.1; 
    height= 56.9;
    holder_diff = 1.25;
    holder_pos = 13;   

        difference() {
            translate([0,0,height/2+wall/2]) {
                hollowbox(width, height, holder_diff, value); 
                holder(width, height, holder_diff, holder_pos, value);
                }
                            
            translate([0,0, 44.2])
                MiniCore2R21();        
            translate([0,0, 31])
                MiniSensorModuleR11();
            translate([0,0, 19])
                MiniSigfoxR21();
            translate([0, 9, 0])
                mountingHoles1xx();            
        }
}

module BCE108r2 (value) { //Mini Battery + Relay + Core R2 + Mini Cover
    width= 33.1; 
    height= 44;
    holder_diff = 1.25;
    holder_pos = 13;   

        difference() {
            translate([0,0,height/2+wall/2]) {
                hollowbox(width, height, holder_diff, value); 
                holder(width, height, holder_diff, holder_pos, value);
                }
                               
            translate([0,0, 31.27])
                MiniCore2R21();
            translate([0,0, 19.05])
                MiniRelay();
            translate([0, 9, 0])
                mountingHoles1xx();            
        }
}

module BCE109r2 (value) { //Mini Battery + Sigfox + Relay + Core R2 + Mini Cover
    width= 33.1; 
    height= 56;
    holder_diff = 1.25;
    holder_pos = 13;   

        difference() {
            translate([0,0,height/2+wall/2]) {
                hollowbox(width, height, holder_diff, value); 
                holder(width, height, holder_diff, holder_pos, value);
                }
                            
            translate([0,0, 43.0])
                MiniCore2R21();        
            translate([0,0, 31])
                MiniRelay();
            translate([0,0, 19])
                MiniSigfoxR21();
            translate([0, 9, 0])
                mountingHoles1xx();            
        }
}
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

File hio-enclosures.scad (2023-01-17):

/* HARDWARIO IoT Kit Enclosure models for 3D print
https://www.hardwario.com/
https://shop.hardwario.com/modules-tags/
https://shop.hardwario.com/enclosures/ 

This project is licensed under the [Attribution-ShareAlike 4.0 International](https://creativecommons.org/licenses/by-sa/4.0/) - see the [LICENSE](LICENSE) file for details.
*/

use <MCAD/boxes.scad>;
use <MCAD/triangles.scad>;
 
//SELECT ENCLOSURE
//Option: "A" = part A; "B" = part B; "C" = cover; "ALL" whole box 
color ("Silver")
//HWE101("ALL"); //Mini Battery + Core + Mini Cover
HWE102("ALL"); //Mini Battery + Sigfox + Core + Mini Cover
//HWE103("ALL"); //Mini Battery + 1-Wire + Core + Mini Cover
//HWE104("ALL"); //Mini Battery + Sigfox + 1-Wire + Core + Mini Cover
//HWE105("ALL"); //Mini Battery + Sensor R1.1 + Core + Cover
//HWE106("ALL"); //Mini Battery + Sigfox + Sensor R1.1 + Core + Cover
//HWE108("ALL"); //Mini Battery + Relay + Core + Mini Cover
//HWE109("ALL"); //Mini Battery + Sigfox + Relay + Core + Mini Cover
//HWE401("ALL"); //1-Wire + Cover
//HWE402("ALL"); //Bridge + Tag
//HWE201("ALL"); //Battery R1.4 + CO2 + Core + Cover
//HWE202("ALL"); //Battery R1.4 + CO2 + Sigfox + Core + Cover
//HWE203("ALL"); //Battery + CO2 + Core + LCD (Tags ouside)
//HWE204("ALL"); //Battery R1.4 + CO2 + Core + LCD (Tags inside)
//HWE205("ALL"); //Battery + Core + Cover
//HWE206("ALL"); //Battery + CO2 + Sigfox + Core + LCD (Tags inside)
//HWE207("B"); //Battery + Sigfox + Core + Cover
//HWE208("ALL"); //Battery + Core + Split + LCD & PIR (or LCD & Climate) & 2x Tag (intside)
//HWE209("ALL"); //Battery + Core + Compact Split + LCD & Climate
//HWE210("ALL"); //Battery + Split Core & Split + LCD & GPS (or PIR & Climate) & No Tag
//HWE211("ALL"); //Battery + Sigfox + Core + LCD (Tags inside)
//HWE301("ALL"); //Power + Core + Cover
//HWE302("ALL"); //Power + Core + Encoder 
//HWE303("ALL"); //Power + Core + Encoder + LCD //TO BE DONE
//HWE304("ALL"); //Power + Sigfox + Core + Cover
//HWE305("ALL"); //Power + Sigfox + CO2 + Core + Cover
//HWE501("ALL"); //Mini Battery + Sensor + Core + Flood Detector
//HWE502("ALL"); //Mini Battery + Sensor + Core + Sigfox + Flood Detector


//RENDER IMAGE FOR PNG EXPORT
//print("HWE101"); // Type enclosure model to render in red color

//CAMERA VIEW SETTING
//    //small enclosure
//    $vpr = [34,0,17];   // view angle
//    $vpt = [0,-5,35];   // view tranlsation
//    $vpd = 250;         // view distance
//    
//    // large enclosure / low
//    $vpr = [34,0,17];   // view angle
//    $vpt = [0,-5,32];   // view tranlsation
//    $vpd = 265;         // view distance
//    
//    // large enclosure / tall
//    $vpr = [34,0,17];   // view angle
//    $vpt = [0,-5,38];   // view tranlsation
//    $vpd = 275;         // view distance

//dimension check
//translate([0,-30,0]) cube([10,10,50]);


/* [Render otions] */
sidesonly=1; // [0:No, 1:Yes] round the sides of the box?
previw_mode = 0; //[0:No, 1:Yes] 1 for faster rendering
step = 8; // resolution of ring corner - STEP in degrees
$fn = 50; // default resolution = 50
  
wall=2.0;  // Wall Thickness
length= 55.7; // enclosure length
cut_length = 16; //Part A / B cut

// Mounting holes params
screw_hole_height = 2.1;
screw_size = 3.2;
screw_hole_angle = 15;
screw_hole_top_size = screw_size+4;
 
//Holder for PCB
holder_w = 0.8;
holder_h = 1;
holder_short = 7; // multiplier of top holder shortcut (=1 the same as bottom holder)
  
// Corner Radius
radius=3.8; // radius
radius_bot=3.8+2.5; //inner radius of bottom
 
//Rubber ring
ring_r = 1;
ring_top_pos = 2.6;
ring_bottom_pos = 2.6;
 
cut_type = 0; // [1: old, 0: new]
 
// Get outside mesurments
/* [Advanced] */
r_MiniUSB=1;
r_wifi_antenna = 4.8;
 
PCB_height=1.1;
fatPCB_height=1.6;
PCB_tolerance = 0.4; //grove tolerance for PCB
MiniPCB_width=33;
PCB_width=88;
PCB_radius=3.8;
 
USBmicro_height=5.7;
USBmicro_width=12;
USBmicro_length=wall/2;
USBmicro_hole=3.5;
USBmicro_hole_span=8.2;

flood_detector_width=10.8;
flood_detector_length=20.7;
flood_detector_contact_width=2;
flood_detector_contact_length=5.5;
 
terminal185mm_height=7.6;
terminal185mm_width=19;
terminal185mm_length=wall;
terminal185mm_upper_recess=1;
terminal185mm_bottom_recess=4;

terminal17mm_height=8.5;
terminal17mm_width=17;
terminal17mm_length=wall;
terminal17mm_upper_recess=2.5;
terminal17mm_bottom_recess=4.8;

terminal15mm_height=7.7;
terminal15mm_width=15.5;
terminal15mm_length=wall;
terminal15mm_upper_recess=1;
terminal15mm_bottom_recess=4.8;

terminal12_3mm_height=7.6;
terminal12_3mm_width=12.6;
terminal12_3mm_length=wall;
terminal12_3mm_upper_recess=1;
terminal12_3mm_bottom_recess=4.1;
 
key_width_wall=0.2;
key_length_wall=wall;
key_height_wall=1.6;
key_x_roof=8.2;
key_y_roof=wall;
key_height_roof=0.35;


module HWE101 (value) { //Mini Battery + Core + Mini Cover
    width= 33.1; 
    height= 32.1;
    holder_diff = PCB_height+PCB_tolerance;
    holder_pos = 13;  

        numberPrint("101",value);
        difference() {
            translate([0,0,height/2+wall/2]) {
                hollowbox(width, height, holder_diff, value);
                holder(width, height, holder_diff, holder_pos, value);
                }
            translate([0,0, 19])
                MiniCore21();
            translate([0, 9, 0])
                mountingHoles1xx();
        }
}
module HWE102 (value) { //Mini Battery + Sigfox + Core + Mini Cover
    width= 33.1;
    height= 44.2;
    holder_diff = PCB_height+PCB_tolerance;
    holder_pos = 13;

        numberPrint("102",value);
        difference() {
            translate([0,0,height/2+wall/2]) {
                hollowbox(width, height, holder_diff, value);
                holder(width, height, holder_diff, holder_pos, value);
                }
            translate([0,0, 31.6-0.4])
                MiniCore21();
            translate([0,0, 19])
                MiniSigfox1();
            translate([0, 9, 0])
                mountingHoles1xx();
        }
}
module HWE103 (value) { //Mini Battery + 1-Wire + Core + Mini Cove
    width= 33.1;
    height= 44.4;
    holder_diff = PCB_height+PCB_tolerance;
    holder_pos = 13;

        numberPrint("103",value);
        difference() {
            translate([0,0,height/2+wall/2]) {
                hollowbox(width, height, holder_diff, value);
                holder(width, height, holder_diff, holder_pos, value);
                }
            translate([0,0, 31.6])
                MiniCore21();
            translate([0,0, 19])
                MiniSensorModuleR10();
            translate([0, 9, 0])
                mountingHoles1xx();
        }
}
module HWE104 (value) { //Mini Battery + Sigfox + 1-Wire + Core + Mini Cover
    width= 33.1;
    height= 57.1;
    holder_diff = PCB_height+PCB_tolerance;
    holder_pos = 13;

        numberPrint("104",value);
        difference() {
            translate([0,0,height/2+wall/2]) {
                hollowbox(width, height, holder_diff, value);
                holder(width, height, holder_diff, holder_pos, value);
                }
                            
            translate([0,0, 44.1])
                MiniCore21();
            translate([0,0, 31.8])
                MiniSensorModuleR10();
            translate([0,0, 18.9])
                MiniSigfox1();
            translate([0, 9, 0])
                mountingHoles1xx();
        }
}
module HWE105 (value) { //Mini Battery + Sensor R1.1 + Core + Cover
    width= 33.1;
    height= 44.2;
    holder_diff = PCB_height+PCB_tolerance;
    holder_pos = 13;

        numberPrint("105",value);
        difference() {
            translate([0,0,height/2+wall/2]) {
                hollowbox(width, height, holder_diff, value);
                holder(width, height, holder_diff, holder_pos, value);
                }
       
            translate([0,0, 31.2])
                MiniCore21();
            translate([0,0, 18.4])
                MiniSensorModuleR11();
            translate([0, 9, 0])
                mountingHoles1xx();
        }
}
module HWE106 (value) { //Mini Battery + Sigfox + Sensor R1.1 + Core + Cover
    width= 33.1;
    height= 56.9;
    holder_diff = PCB_height+PCB_tolerance;
    holder_pos = 13;

        numberPrint("106",value);
        difference() {
            translate([0,0,height/2+wall/2]) {
                hollowbox(width, height, holder_diff, value);
                holder(width, height, holder_diff, holder_pos, value);
                }
                            
            translate([0,0, 44.2])
                MiniCore21();
            translate([0,0, 31])
                MiniSensorModuleR11();
            translate([0,0, 19])
                MiniSigfox1();
            translate([0, 9, 0])
                mountingHoles1xx();
        }
}

module HWE108 (value) { //Mini Battery + Relay + Core + Mini Cover
    width= 33.1;
    height= 44;
    holder_diff = PCB_height+PCB_tolerance;
    holder_pos = 13;
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

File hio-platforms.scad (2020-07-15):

/* 3D print platform for ABB enclosure and HARDWARIO IoT Kit

https://www.hardwario.com/
https://shop.hardwario.com/modules/

This project is licensed under the [Attribution-ShareAlike 4.0 International](https://creativecommons.org/licenses/by-sa/4.0/) - see the [LICENSE](LICENSE) file for details.
*/


$fn=50; //render detail setting


//ABB-00852 inner dimesnsion
abbX=150;   //x dimension
abbY=107;   //y dimension
a=27;       //box corner cut a dimension 
b=27;       //box corner cut b dimension
r=11;       //box corner cut radius

nodeH=12;   //installation height
h=5;       //platform height


//HARDWRIO module cut dimension
nodeX=88.6;     //x dimension
nodeY=55.6;     //y dimension
offsetX=23-15;  //x offset poition
nodeRad=2.5;    // corner radius
pcbH=1.5;       //module PCB heght


HWE901(); //ABB-00852 

//Platform can be used for mounting HARDWARIO IoT Kit module into ABB enclosure (up to 4 modules). 
//As a base floor module use Battery Module or Power Module 
module HWE901(){  
    difference(){
            cutedBase(abbX,abbY,a,b,h);             //base  platform
            nodecut(nodeX,nodeY,nodeRad,h+0.2,offsetX); //cut for module
            screwcut();                             //screw holes
            translate([0,0,-0.1]) gridcut(h+0.2);   //base platform opening
    }
    difference(){
        nodepole(nodeX,nodeY,offsetX,nodeH,pcbH);   //module spacer
        translate([-nodeY/2+offsetX,-15/2,nodeH-4]) cube([nodeY,15,4]);    // opening cut for Power Module
        nodescrew(offsetX,nodeH);                   //module spacer screw holes
    }    
    translate([-nodeY/2+offsetX,-12/2,0]) cube([nodeY,12,4]); //rail under module cut
    //ampmount(offsetX,0,nodeH); // optional holder for exetsion module
}

module cutedBase(A,B,a,b,h){
    difference(){
        base(abbX,abbY,h);
        translate([0,0,-0.1]) basecut(a,b,r,h+0.2);
    }
}
  
module base(a,b,h){
    translate([-a/2,-b/2,0]) cube([a,b,h]);
}
    
module basecut(a,b,r,h){
    translate([-abbX/2,-abbY/2,0]) fullpool(a,a,r,h);
    translate([+abbX/2,-abbY/2,0]) fullpool(a,a,r,h);
    translate([-abbX/2,+abbY/2,0]) fullpool(a,a,r,h);    
    translate([+abbX/2,+abbY/2,0]) fullpool(a,a,r,h);    
}

module nodecut(nodeX,nodeY,nodeRad,h,offsetX){ 
 translate([offsetX,0,-0.1])rotate([0,0,90])fullpool(nodeX,nodeY,nodeRad,h+0.1);
}
module screwcut(){
    r1=4.2/2; //srew hole
    r2=7.5/2; //screw head
    deep=0.6; //screw head deep
    
    //large hole
    translate([+118/2,+75/2,-0.1])  cylinder(r=13/2,h=3+0.1);
    translate([-118/2,+75/2,-0.1])  cylinder(r=13/2,h=3+0.1);
    translate([+118/2,-75/2,-0.1])  cylinder(r=13/2,h=3+0.1);
    translate([-118/2,-75/2,-0.1])  cylinder(r=13/2,h=3+0.1);

    //screw hole bottom
    translate([+(118/2+7),+(75/2-9),-0.1])  cylinder(r=7/2,h=3+0.1);
    translate([-(118/2+7),+(75/2-9),-0.1])  cylinder(r=7/2,h=3+0.1);
    translate([+(118/2+7),-(75/2-9),-0.1])  cylinder(r=7/2,h=3+0.1);
    translate([-(118/2+7),-(75/2-9),-0.1])  cylinder(r=7/2,h=3+0.1);
    
    //screw hole
    translate([+(118/2+7),+(75/2-9),-0.1])  cylinder(r=r1,h=h+0.1);
    translate([-(118/2+7),+(75/2-9),-0.1])  cylinder(r=r1,h=h+0.1);
    translate([+(118/2+7),-(75/2-9),-0.1])  cylinder(r=r1,h=h+0.1);
    translate([-(118/2+7),-(75/2-9),-0.1])  cylinder(r=r1,h=h+0.1);    
    
    //screw hole top
    translate([+(118/2+7),+(75/2-9),h-deep-0.1])  cylinder(r=r2,h=deep+0.2);
    translate([-(118/2+7),+(75/2-9),h-deep-0.1])  cylinder(r=r2,h=deep+0.2);
    translate([+(118/2+7),-(75/2-9),h-deep-0.1])  cylinder(r=r2,h=deep+0.2);
    translate([-(118/2+7),-(75/2-9),h-deep-0.1])  cylinder(r=r2,h=deep+0.2);    
    
    //rectangle hole bottom
    translate([+(118/2+7),+(75/2-14+0.5),-0.1]) fullpool(11,11,0.7,3+0.1);
    translate([+(118/2+7),-(75/2-14+0.5),-0.1]) fullpool(11,11,0.7,3+0.1);
    translate([-(118/2+7),+(75/2-14+0.5),-0.1]) fullpool(11,11,0.7,3+0.1);
    translate([-(118/2+7),-(75/2-14+0.5),-0.1]) fullpool(11,11,0.7,3+0.1);
}  

module gridcut(h){ 
    x=88/3.2;   //a length
    y=55/3.2;   //b lenght
    rad=2.5;
    dx=1.43*x;
    dy=1.76*y;
        
    translate([50,0,0]) fullpool(y,x,rad,h);
    translate([50,-dy,0]) fullpool(y,x,rad,h);
    translate([50,dy,0]) fullpool(y,x,rad,h);
    
    translate([-dx,0,0]) fullpool(y,x,rad,h);
    translate([-dx,-dy,0]) fullpool(y,x,rad,h);
    translate([-dx,dy,0]) fullpool(y,x,rad,h);    
    
    translate([-1.57*dx,0,0]) fullpool(55/2.81,x,rad,h);    
}
module nodepole(nodeX,nodeY,offsetX,h,pcbH){
    translate ([offsetX-nodeY/2+2,0,0])fullpool(7.2+4.5,34,2.5,h-pcbH);
    translate ([offsetX+nodeY/2-2,0,0])fullpool(7.2+4.5,34,2.5,h-pcbH);    
}

module nodescrew(offsetX,h){
    //node screw holes
    dy=25.4;    //y difference
    dx=47.4;    //x difference
    r=2.9/2;     //screw diameter
    
    translate([+(dx/2+offsetX),+(dy/2),-0.1])  cylinder(r=r,h=h+0.2);
    translate([(-dx/2+offsetX),+(dy/2),-0.1])  cylinder(r=r,h=h+0.2);
    translate([+(dx/2+offsetX),-(dy/2),-0.1])  cylinder(r=r,h=h+0.2);
    translate([(-dx/2+offsetX),-(dy/2),-0.1])  cylinder(r=r,h=h+0.2);
}
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

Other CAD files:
stl-models/HWE304A.stl
stl-models/HWE201B.stl
stl-models/HWE304B.stl
stl-models/HWE201A.stl
stl-models/HWE101B.stl
stl-models/HWE102B.stl
stl-models/HWE103A.stl
stl-models/HWE103B.stl
stl-models/HWE104A.stl
stl-models/HWE104B.stl
stl-models/HWE105A.stl
stl-models/HWE105B.stl
stl-models/HWE106B.stl
stl-models/HWE108A.stl
stl-models/HWE108B.stl
stl-models/HWE109A.stl
stl-models/HWE202A.stl
stl-models/HWE202B.stl
stl-models/HWE203A.stl
stl-models/HWE203B.stl
stl-models/HWE204A.stl
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

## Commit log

2017-09-14 Add wide enclosures
    [bce201a.stl, bce201b.stl, bce301a.stl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]
2017-09-14 Add model BCE101
    [bce101a.stl, bce101b.stl]
2017-10-01 Add BCE202
    [bce202a.stl, bce202b.stl]
2017-10-17 Add bce501 flood sensor enclosure, add pictures, O-rings specification and comments
    [bce501a.stl, bce501b.stl]
2017-12-08 Fix and update enclosure bce301, delete bce302
    [bce301a.stl, bce301b.stl]
2018-01-15 Add enclosure bce303 and bce203
    [bce303a.stl, bce303b.stl]
2018-02-03 Improve BCE101, add model BCE103, BCE203, 3mm LED holder, PIR Cover
    [bce101a.stl, bce101b.stl, bce103a.stl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]
2018-02-11 Improve model BCE104A and BCE104B
    [bce104a.stl, bce104b.stl]
2018-04-12 Add enclosure bce-204, pir-sc, optimize models bce201, bce301
    [bce204a.stl, bce204b.stl, bce204c.stl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]
2018-04-12 Add picture of enclosure bce204
2018-04-12 Edit picture of enclosure bce204
2018-06-28 Add enclosure BCE101v2 optimized for Core Module R2
    [bce101v2a.stl, bce101v2b.stl]
2018-06-28 Add revision subfix
    [bce101a-r1.stl, bce101a-r2.stl, bce101b-r1.stl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]
2018-09-04 Add folder stl-models and openscad-models
    [bce101a-r1.stl, bce101a-r2.stl, bce101b-r1.stl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]
2019-01-29 added common openscad model
    [bc-enclosures.scad]
2019-02-21 Edit bc-enslosures.scad
    [bc-enclosures.scad]
2019-03-12 fix antenna position for sigfox module; move sensor R1.1 connector hole; fix A and B parts gap
    [bc-enclosures.scad]
2019-04-11 fix hole usb micro BCE301r2; edge increase BCE101r2, BCE106r2, BCE301r2, BCE304r2, BCE305r2
    [bc-enclosures.scad]
2019-04-15 add BCE103r2, fix hole BCE105r2
    [bc-enclosures.scad]
2019-05-30 add BCE104, BCE106, BCE108, BCE109, BCE201, BCE202, BCE205, BCE301
    [bc-enclosures.scad]
2019-07-16 fix rim
    [bc-enclosures.scad]
2019-07-18 add BCE210r2
    [bc-enclosures.scad]
2019-12-20 add BCE210, BCE204, BCE203, BCE206, BCE208, BCE209, BCE302, BCE303, BCE121, BCE502; fix new CO2 module (BCE201, BCE202, BCE305)
    [bc-enclosures.scad]
2020-02-04 Add parameter length_tolerance to cover_miniPCB, add enclosure BCE2011r2
    [bc-enclosures.scad]
2020-03-06 Edit enclosure bce122 - Bridge Module, add stl models
    [bc-enclosures.scad, bce122a.stl, bce122b.stl]
2020-03-11 Add Enclosure BCE202r14
    [BCE202r14A.stl, BCE202r14B.stl, bc-enclosures.scad]
2020-03-29 Rename bc-enclosures to hio-enclosures, update models, pictures and readme.md
    [BCE101A-r1.stl, BCE101A-r2.stl, BCE101B-r1.stl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]
2020-07-15 Tune enclosure HWE207 and add enclosure HWE207
    [HWE207A.stl, HWE207B.stl, HWE211A.stl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]
2020-07-15 Add hio-platforms.scad and model HWE901 with ABB 00852 platform
    [HWE901.stl, hio-platforms.scad]
2023-01-17 Edit hio-enclosure.scad
    [hio-enclosures.scad]
